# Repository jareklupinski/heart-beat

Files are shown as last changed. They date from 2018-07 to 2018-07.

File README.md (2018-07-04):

# heart-beat
A redesigned 808-synth clone

After hearing Ke$ha ask "do i make your heart beat like an 808 drum", I realized that I had no idea what an 808 drum sounded like. The parts to build a clone aren't that expensive.

This design was built, tested, and is working. It had an issue with the Accent ability that needs attention.

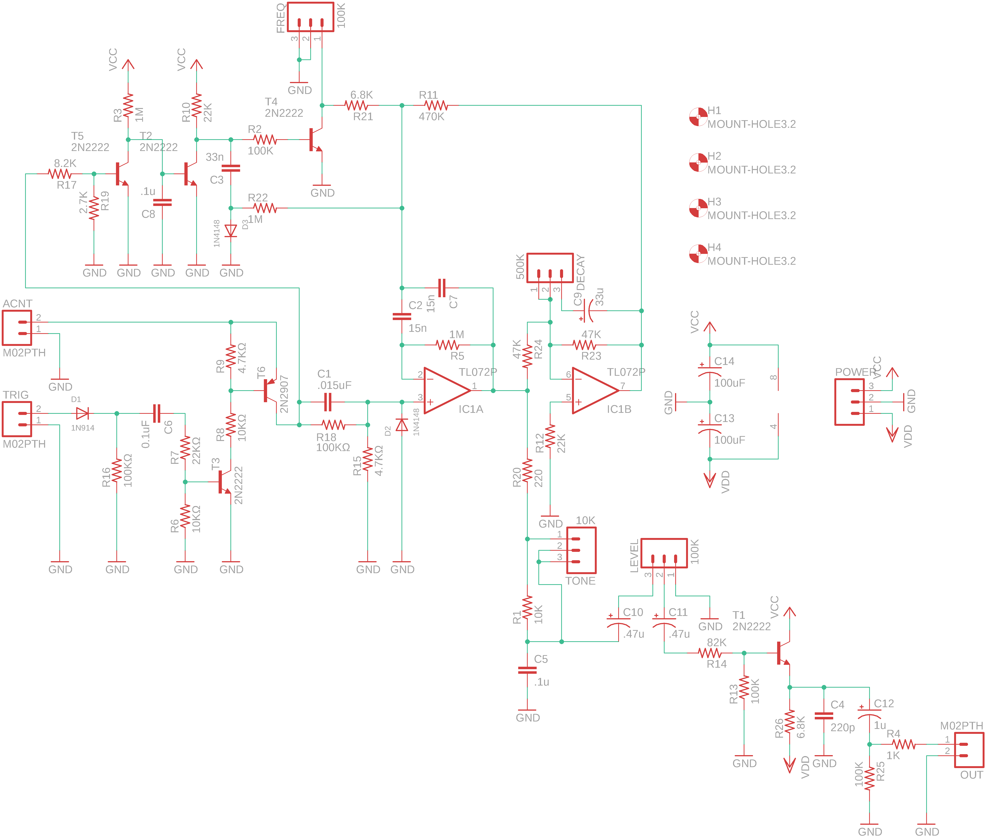
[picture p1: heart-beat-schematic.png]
schematic

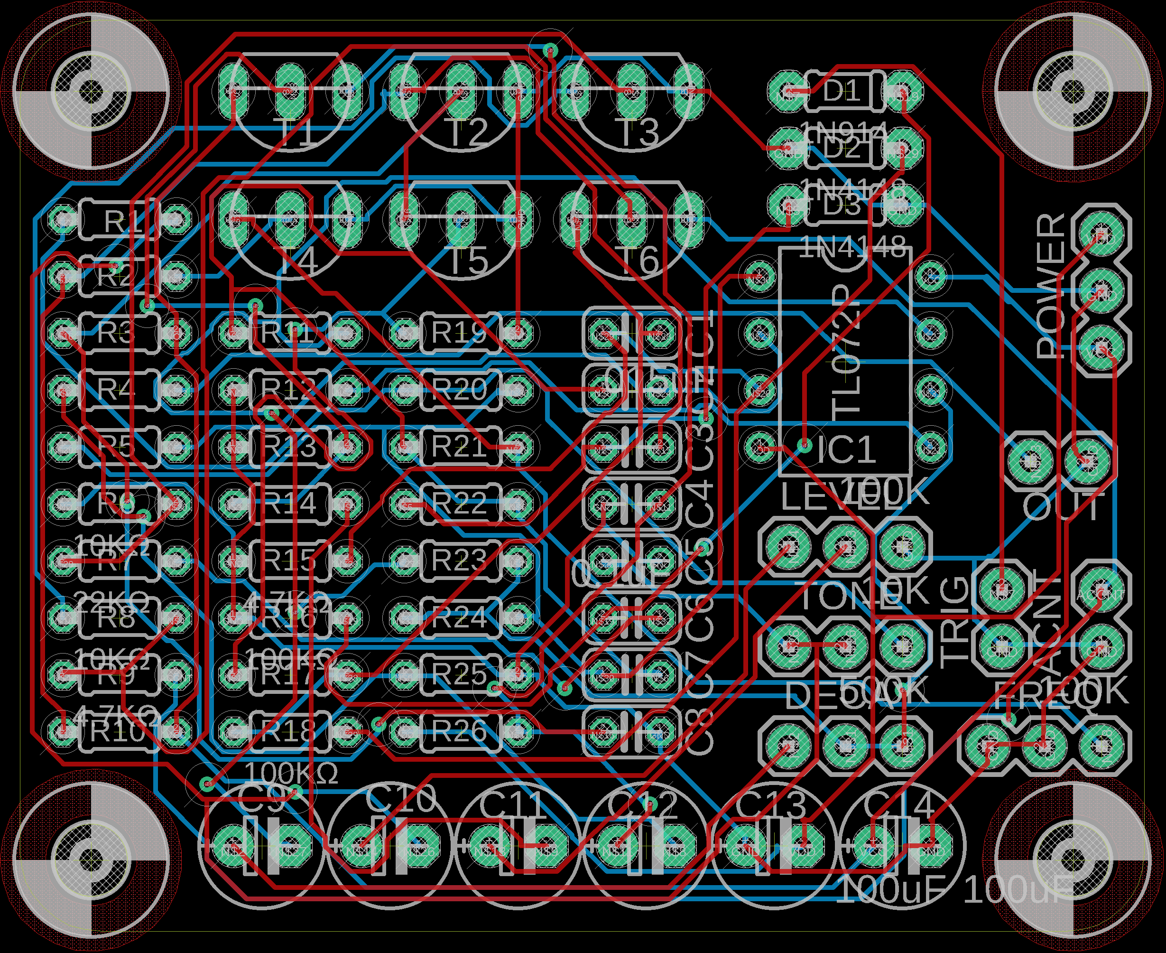
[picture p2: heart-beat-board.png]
board


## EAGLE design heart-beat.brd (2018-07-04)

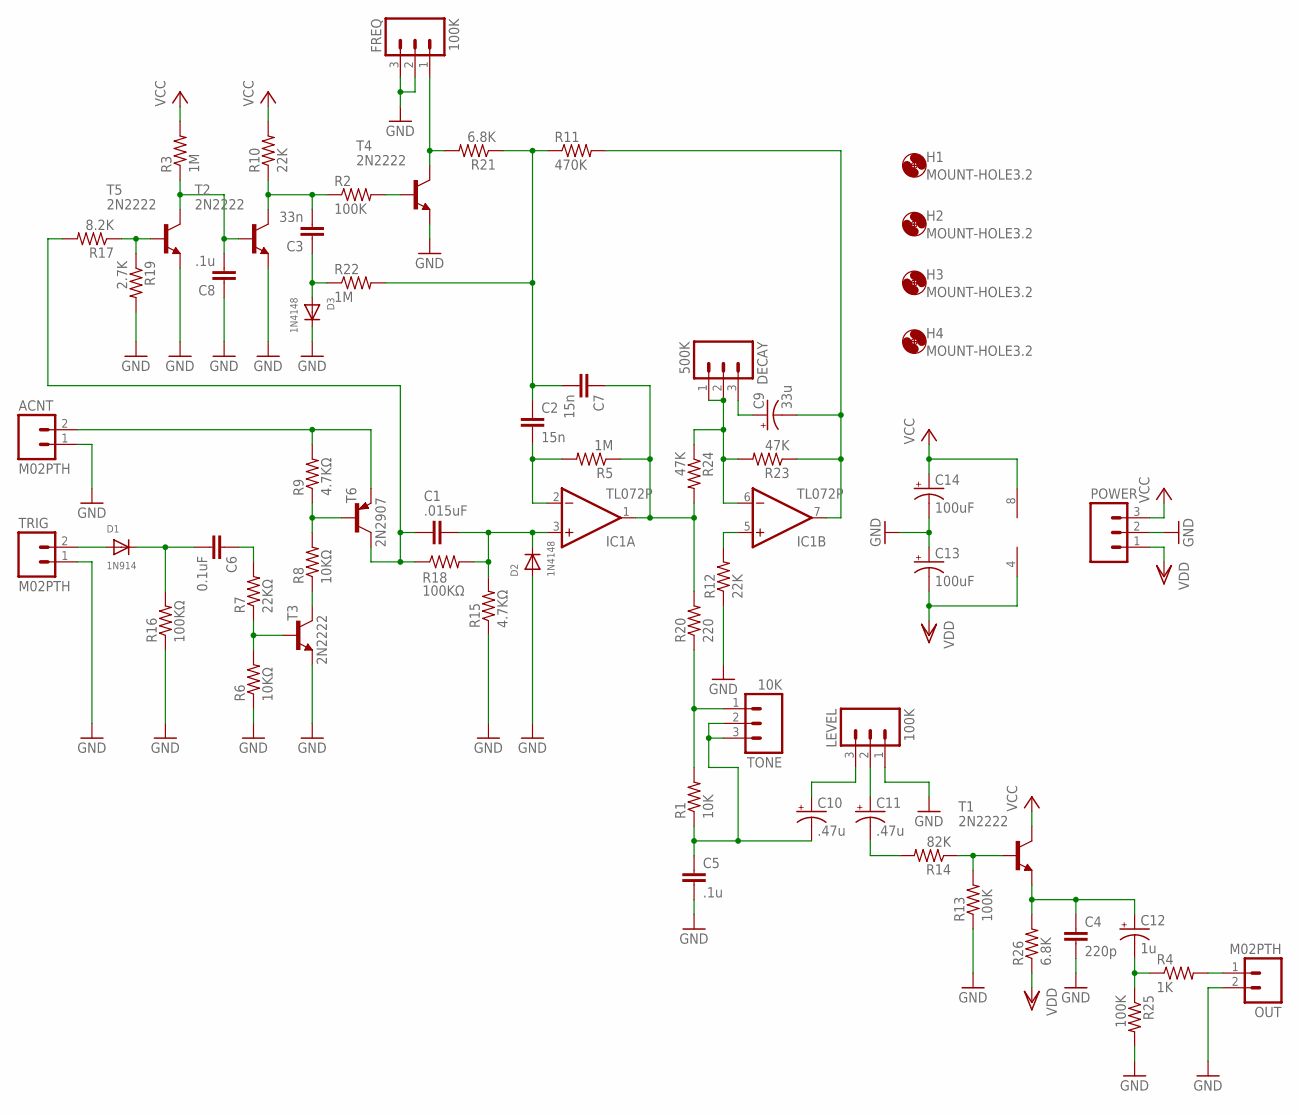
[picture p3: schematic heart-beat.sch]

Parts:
ACNT: M02PTH; 1X02
C1: .015uF; C025-024X044
C2, C7: 15n; C025-024X044
C3: 33n; C025-024X044
C4: 220p; C025-024X044
C5, C8: .1u; C025-024X044
C6: 0.1uF; C025-024X044
C9: 33u; E2,5-6E
C10, C11: .47u; E2,5-6E
C12: 1u; E2,5-6E
C13, C14: 100uF; E2,5-6E
D1: 1N914; 1N4148
D2, D3: 1N4148
DECAY: 500K; 1X03
FREQ: 100K; 1X03
H1, H2, H3, H4: MOUNT-HOLE3.2; 3,2
IC1: TL072P; DIL08
LEVEL: 100K; 1X03
OUT: M02PTH; 1X02
POWER: M03PTH; 1X03
R1: 10K; 0204/5
R2, R13, R25: 100K; 0204/5
R3, R5, R22: 1M; 0204/5
R4: 1K; 0204/5
R6, R8: 10KΩ; 0204/5
R7: 22KΩ; 0204/5
R9, R15: 4.7KΩ; 0204/5
R10, R12: 22K; 0204/5
R11: 470K; 0204/5
R14: 82K; 0204/5
R16, R18: 100KΩ; 0204/5
R17: 8.2K; 0204/5
R19: 2.7K; 0204/5
R20: 220; 0204/5
R21, R26: 6.8K; 0204/5
R23, R24: 47K; 0204/5
T1, T2, T3, T4, T5: 2N2222; TO92-EBC-OVAL
T6: 2N2907; TO92-EBC-OVAL
TONE: 10K; 1X03
TRIG: M02PTH; 1X02

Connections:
ACCNT: ACNT.2, R9.2, T6.E
GND: ACNT.1, C4.2, C5.2, C8.1, C13.+, C14.-, D2.A, D3.K (C), FREQ.2, FREQ.3, LEVEL.1, OUT.2, POWER.2, R6.1, R12.1, R13.1, R15.1, R16.1, R19.2, R25.2, T2.E, T3.E, T4.E, T5.E, TRIG.1
unnamed: R17.1, R19.1, T5.B
unnamed: C9.+, DECAY.3
unnamed: R13.2, R14.1, T1.B
unnamed: R8.2, R9.1, T6.B
unnamed: C3.1, D3.A, R22.1
unnamed: C2.1, C7.2, R11.1, R21.1, R22.2
unnamed: D1.A, TRIG.2
unnamed: C12.-, R4.1, R25.1
unnamed: C11.-, R14.2
unnamed: R8.1, T3.C
unnamed: C4.1, C12.+, R26.2, T1.E
unnamed: R2.2, T4.B
unnamed: C11.+, LEVEL.2
unnamed: C10.+, LEVEL.3
unnamed: C3.2, R2.1, R10.1, T2.C
unnamed: C8.2, R3.1, T2.B, T5.C
unnamed: FREQ.1, R21.2, T4.C
unnamed: C6.2, D1.K (C), R16.2
unnamed: R6.2, R7.1, T3.B
unnamed: IC1.5 (+IN), R12.2
unnamed: R1.2, R20.1, TONE.1
unnamed: OUT.1, R4.2
unnamed: C2.2, IC1.2 (-IN), R5.2
unnamed: C5.1, C10.-, R1.1, TONE.2, TONE.3
unnamed: C9.-, IC1.7 (OUT), R11.2, R23.1
unnamed: C1.2, R17.2, R18.1, T6.C
unnamed: C1.1, D2.K (C), IC1.3 (+IN), R15.2, R18.2
unnamed: C7.1, IC1.1 (OUT), R5.1, R20.2, R24.2
unnamed: DECAY.1, DECAY.2, IC1.6 (-IN), R23.2, R24.1
unnamed: C6.1, R7.2
VCC: C14.+, IC1.8 (V+), POWER.3, R3.2, R10.2, T1.C
VDD: C13.-, IC1.4 (V-), POWER.1, R26.1

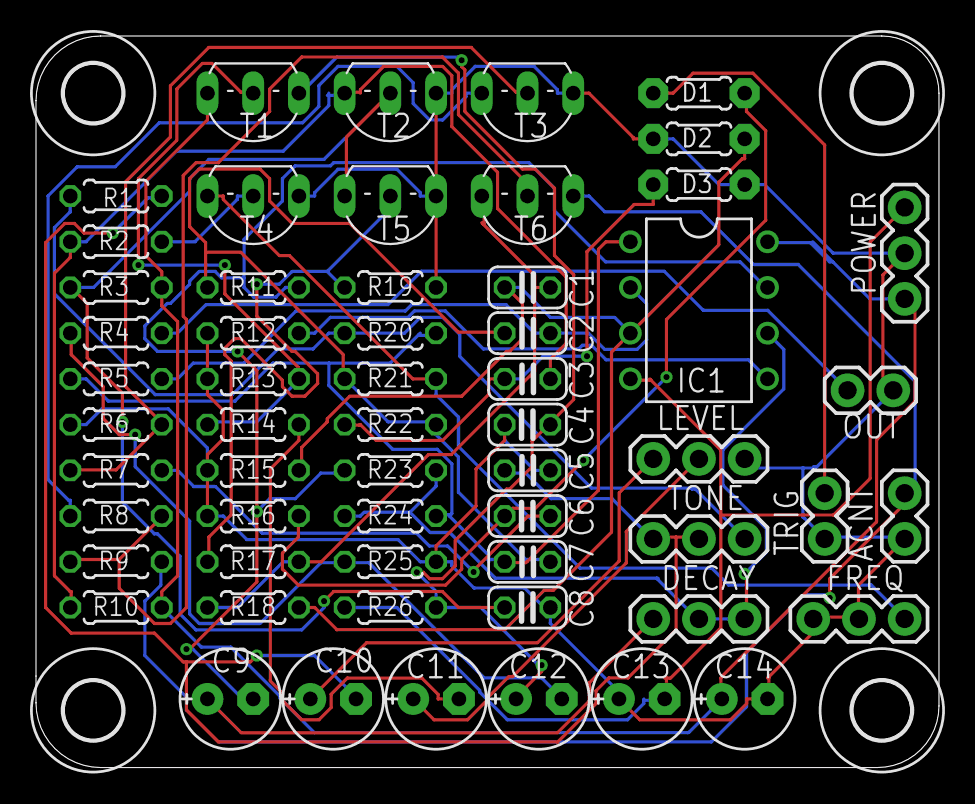
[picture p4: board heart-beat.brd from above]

Board: 2 copper layers, 50.2 x 40.6 mm, 62 parts (0 on the bottom side), 34 nets.

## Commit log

2018-07-04 prototype tested- working
2018-07-04 added pictures of board and schematic

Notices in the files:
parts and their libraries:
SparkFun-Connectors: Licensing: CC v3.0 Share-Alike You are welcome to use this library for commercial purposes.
